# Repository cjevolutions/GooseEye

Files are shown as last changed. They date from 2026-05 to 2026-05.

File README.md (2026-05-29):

# GooseEye hardware — **start here**

You are in the right place. This repository is a **step-by-step kit** for building the GooseEye truck-bed distance sensor: a small box with a laser rangefinder and a Bluetooth chip that talks to the GooseEye phone app (the app is **not** in this repo).

**You do not need** prior experience with GitHub or programming. You **do** need the capabilities below — read them **before** you buy parts.

---

## Requirements (read this before ordering parts)

If you cannot check off every **must have** row, finish that gap first or this build will stall halfway.

### Must have

| Requirement | What it means for you |
|---|---|
| **A 3D-printed enclosure** | The sensor box is **not** sold ready-made. You get a free computer model ([`v3 Case.step`](docs/v3%20Case.step)) and must produce a physical plastic case using **one** of the options below. |
| **3D printer *or* print service** | **Option A — Own printer:** FDM printer (Bambu, Prusa, Creality, etc.), slicer software, and filament (**PETG** or **ASA** recommended for sun/heat in a truck bed). **Option B — No printer:** Upload the file to an online print service (e.g. [Craftcloud](https://craftcloud3d.com/)) or a local makerspace/library and pay someone to print it. Budget roughly **$15–60 USD** for a service print, plus shipping and wait time. → **[How to print the case](docs/PRINT-THE-CASE.md)** |
| **Soldering** | Every wire between the truck power, converter, ESP32, MOSFET, and LiDAR is **soldered**. You need a soldering iron, solder, and heat-shrink (or tape). First-time solderers can do this — plan a slow evening. |
| **Computer (once)** | Mac or Windows PC with internet, to install **PlatformIO** and run **one copy-paste command** that loads firmware onto the ESP32. A **USB-C data cable** (not charge-only) connects the board to the PC. |
| **Truck 12 V power** | A fused tap on the vehicle **12 V** accessory/battery circuit to feed the buck converter. Wiring with the **engine off** for the first hookup. |
| **Smartphone with Bluetooth** | To test the sensor (free apps: **nRF Connect** or **LightBlue**). The GooseEye **phone app** is separate from this repo but is what you use day-to-day when driving. |
| **Basic hand tools** | Wire stripper, screwdriver for **2 mm** LiDAR screws, multimeter strongly recommended. |

### Strongly recommended

| Item | Why |
|---|-----|
| **Inline fuse** on 12 V | Protects the truck wiring if something shorts |
| **Silicone sealant** + optional **hot glue gun** | Seals lid gaps and the wire exit against rain/dust |
| **Help or a second pair of hands** | Holding wires while soldering is easier with two people |

### You do **not** need

- A GitHub account (you can download a ZIP)
- Programming experience (no code to write)
- A machine shop or CNC (printing is enough)
- To understand the text inside the `.step` file ([that is not code](docs/PRINT-THE-CASE.md))

### Time and cost (rough planning)

| | Estimate |
|---|---|
| **Your time** | One **weekend** if new to soldering; faster if experienced |
| **Amazon electronics** | About **$80–150 USD** depending on what you already own |
| **Case** | Filament + electricity if self-printed; **$15–60+** if using a print service |
| **Tools one-time** | Iron + solder + multimeter if you do not own them |

**Ready?** Continue to the [parts shopping list](#parts-to-order-shopping-list) below, then the [build path](#the-build-path--follow-in-order).

---

## Parts to order (shopping list)

Order these **after** the [requirements](#requirements-read-this-before-ordering-parts) above make sense for you. Check each box when it arrives.

| | Part | Qty | Notes | Where to buy |
|---|---|:---:|---|---|
| ☐ | Benewake waterproof TFmini LiDAR | 1 | 4-wire UART rangefinder | [**Amazon →**](https://www.amazon.com/Benewake-Distance-Waterproof-Anti-dust-Raspberry/dp/B08D3D63QZ) |
| ☐ | Seeed XIAO ESP32-S3 | 1 | Includes snap-on **U.FL WiFi antenna** | [**Amazon →**](https://www.amazon.com/ESP32S3-2-4GHz-Dual-core-Supported-Efficiency-Interface/dp/B0BYSB66S5) |
| ☐ | DC buck converter (12 V → 5 V) | 1 | Adjust trim to **5.00 V** before load | [**Amazon →**](https://www.amazon.com/dp/B0F1WB3LJ5) |
| ☐ | MOSFET switch module | 1 | Switches LiDAR power in sleep mode | [**Amazon →**](https://www.amazon.com/dp/B0DZP27C2N) |
| ☐ | Wire (main harness) | 1 roll | Match gauge to your truck run length | [**Amazon →**](https://www.amazon.com/dp/B0C5T5G2NH) |
| ☐ | 3D-printed case (v3) | 1 | Print at home **or** use a print service — not sold on Amazon | [**How to print**](docs/PRINT-THE-CASE.md) · [**Download file**](https://github.com/cjevolutions/GooseEye/raw/main/docs/v3%20Case.step) |
| ☐ | 2 mm screws (LiDAR to case) | 4+ | Length ≈ 6–12 mm for your print | [**Amazon (example pack) →**](https://www.amazon.com/s?k=m2+screw+kit) · hardware store |

**Also pick up** (soldering, sealing, truck install)

| | Item | Why | Where to buy |
|---|---|-----|---|
| ☐ | Soldering iron + solder + heat-shrink | Wire joints | [**Amazon (kit example) →**](https://www.amazon.com/s?k=soldering+iron+kit) · [tool details](docs/ASSEMBLY.md#3-tools-and-supplies) |
| ☐ | USB-C **data** cable | Flash firmware — not charge-only | [**Amazon (USB-C data cable) →**](https://www.amazon.com/s?k=usb-c+data+cable) |
| ☐ | Multimeter | Check 5 V before powering boards | [**Amazon →**](https://www.amazon.com/s?k=digital+multimeter) |
| ☐ | Silicone sealant (100% silicone, clear outdoor) | Seal lid + wire exit | [**Amazon →**](https://www.amazon.com/s?k=clear+silicone+sealant+outdoor) |
| ☐ | Hot glue gun + glue sticks | Optional extra sealing | [**Amazon →**](https://www.amazon.com/s?k=hot+glue+gun) |
| ☐ | Inline blade fuse + holder (12 V) | Strongly recommended | [**Amazon →**](https://www.amazon.com/s?k=12v+blade+fuse+holder+inline) |
| ☐ | PETG or ASA filament | **Only if you print the case at home** | [**Amazon (PETG example) →**](https://www.amazon.com/s?k=petg+filament+1.75) |
| ☐ | Online 3D print service | **If you do not own a printer** | [Craftcloud](https://craftcloud3d.com/) · [Shapeways](https://www.shapeways.com/) |

Full detail and optional items: [Assembly guide §4 — Bill of materials](docs/ASSEMBLY.md#4-bill-of-materials)

**When parts arrive →** start the [build path](#the-build-path--follow-in-order) at step **0**.

### About the case file (`v3 Case.step`)

That file is a **3D blueprint**, not program code. If GitHub shows a wall of text, **close the tab** and open **[How to print the case](docs/PRINT-THE-CASE.md)** — it explains download, slicer, and print orientation in plain language.

---

## What you are making (30 seconds)

A waterproof LiDAR measures distance to your trailer. A **Seeed XIAO ESP32-S3** board sends that distance over **Bluetooth** to your phone. Everything runs from your truck’s **12 V** power, converted to safe **5 V** inside a **3D-printed case** you provide (home printer or print service). You will **solder wires** and **plug the board into your computer once** to load the firmware.

---

## New to GitHub? You only need the files

You **do not** need a GitHub account to build this. You do **not** need to learn git.

**Option A — Download as ZIP (easiest)**

1. Open this page: [github.com/cjevolutions/GooseEye](https://github.com/cjevolutions/GooseEye)
2. Click the green **Code** button.
3. Click **Download ZIP**.
4. Double-click the ZIP on your computer to unpack it.
5. You now have a folder named `GooseEye-main` (or similar). **That folder is your project.** All paths below assume you are inside it.

**Option B — Clone (only if you already use git)**

```text
git clone git@github.com:cjevolutions/GooseEye.git
cd GooseEye
```

The rest of this README lives inside that folder.

---

## The build path — follow in order

Check off each step. **Next** links take you to the right document and section.

| Step | What you do | Open this next |
|:----:|---|---|
| **0** | Confirm [requirements](#requirements-read-this-before-ordering-parts) & read safety | → [Safety & tools](docs/ASSEMBLY.md#2-safety) |
| **1** | Buy / gather all parts | → [Shopping list](#parts-to-order-shopping-list) · [Full BOM](docs/ASSEMBLY.md#4-bill-of-materials) |
| **2** | See what connects to what (read before soldering) | → [Wiring diagram](docs/wiring-diagram.md) |
| **3** | Print the enclosure | → [**Print the case — start here**](docs/PRINT-THE-CASE.md) (then [assembly §9](docs/ASSEMBLY.md#9-enclosure-assembly-v3-case)) |
| **4** | Snap on WiFi antenna, then solder the harness | → [Soldering steps](docs/ASSEMBLY.md#7-soldering-the-harness) |
| **5** | Power on at the bench (no truck install yet) | → [Bench test](docs/ASSEMBLY.md#8-bench-test-before-truck-install) |
| **6** | Install the flash tool on your computer | → [Install PlatformIO](docs/ASSEMBLY.md#install-platformio) |
| **7** | Load firmware onto the XIAO (one script) | → [Flash firmware](docs/ASSEMBLY.md#upload) + [Script help](#running-the-flash-script-first-timers) below |
| **8** | Confirm Bluetooth with your phone | → [Verify BLE](docs/ASSEMBLY.md#11-verify-ble) |
| **9** | Mount parts in the case | → [Enclosure assembly](docs/ASSEMBLY.md#9-enclosure-assembly-v3-case) |
| **10** | Install in the truck | → [Truck installation](docs/ASSEMBLY.md#12-truck-installation) |
| **11** | Something wrong? | → [Troubleshooting](docs/ASSEMBLY.md#13-troubleshooting) |

**Full single document (printable):** [docs/ASSEMBLY.md](docs/ASSEMBLY.md) — same content as the table above, with more detail in each section.

---

### Step 0 → Start the assembly guide

Open **[docs/ASSEMBLY.md — section 1](docs/ASSEMBLY.md#1-what-you-are-building)** and read sections **1 (what you are building)** and **2 (safety)**.

Then continue to **section 3 (tools)**. Order anything missing from the [shopping list above](#parts-to-order-shopping-list).

**Next:** [Wiring diagram →](docs/wiring-diagram.md)

---

### Step 2 → Wiring (look at diagrams before you solder)

Open **[docs/wiring-diagram.md](docs/wiring-diagram.md)**. You do not need to memorize it; keep it open while you solder.

Key idea: truck **12 V** → **buck converter** → **5 V** to the XIAO **5V / VBUS** pad (board may say **VBUS**, not “5V”) and to a **MOSFET** that switches LiDAR power. UART wires go XIAO **D9/D10** ↔ LiDAR white/green.

**Next:** [Print the case →](docs/ASSEMBLY.md#3d-printing-the-case)

---

### Step 4 → Soldering & antenna

In **[docs/ASSEMBLY.md section 7](docs/ASSEMBLY.md#7-soldering-the-harness)**:

1. **[§7.0](docs/ASSEMBLY.md#step-70--xiao-wifi-antenna-before-wiring)** — Press the small **U.FL antenna** onto the tiny RF port on the XIAO (press straight down; it will feel stiff until it snaps).
2. **§7.1–7.6** — Solder buck, XIAO power, MOSFET, and LiDAR wires.

**Next:** [Bench test →](docs/ASSEMBLY.md#8-bench-test-before-truck-install)

---

### Steps 6–7 → Computer setup and firmware

You are **loading a program** onto the XIAO so it can speak Bluetooth. You are not “coding” — you run one prepared script.

1. Read **[Install PlatformIO](docs/ASSEMBLY.md#install-platformio)** in the assembly guide (Mac: Homebrew; Windows: installer from platformio.org).
2. Plug in the XIAO with a **USB-C data cable** (not charge-only).
3. Follow **[Upload / flash](docs/ASSEMBLY.md#upload)** or use the [script instructions below](#running-the-flash-script-first-timers).

**Next:** [Verify BLE on your phone →](docs/ASSEMBLY.md#11-verify-ble)

---

### Steps 9–10 → Case and truck

**[Enclosure assembly](docs/ASSEMBLY.md#9-enclosure-assembly-v3-case)** — LiDAR on **2 mm screws**, electronics inside, lid against the truck bed, wire out the bottom. Then **[seal gaps with silicone and/or a hot glue gun](docs/ASSEMBLY.md#weather-sealing-silicone-andor-hot-glue)** (lid seam, wire exit, pinholes) before the truck gets wet.

**[Truck installation](docs/ASSEMBLY.md#12-truck-installation)** — fuse, strain relief, clear line of sight to the trailer.

---

## Running the flash script (first timers)

A **script** is a small file of instructions for your computer. You open a **terminal** (text window), go to the project folder, and paste one command. The computer builds and uploads the firmware to the XIAO.

### Mac

1. Open **Terminal** (Spotlight: type `Terminal`, press Enter).
2. Go to your project folder (adjust the path if your folder is on the Desktop):

```bash
cd ~/Downloads/GooseEye-main
```

If you unpacked the ZIP somewhere else, drag the folder into the Terminal window after typing `cd ` — it will fill in the path.

3. Allow the script to run (only needed once):

```bash
chmod +x scripts/flash-firmware.sh
```

4. Run the flasher:

```bash
./scripts/flash-firmware.sh
```

5. Wait until it says **Done**. If it cannot find the board, unplug/replug USB or see [Troubleshooting](docs/ASSEMBLY.md#13-troubleshooting).

**What `chmod` means:** “This file is allowed to run.” **What `./scripts/...` means:** “Run the flash script in the `scripts` folder.”

### Windows

1. Install [PlatformIO](https://platformio.org/install/cli) first (see assembly guide).
2. Open **PowerShell** or **Command Prompt**.
3. Go to the folder:

```powershell
cd Downloads\GooseEye-main
```

4. Run PlatformIO directly (Windows does not require `chmod`):

```powershell
cd firmware
pio run -t upload
```

If upload fails, open Device Manager, note the **COM port** (e.g. `COM5`), then:

```powershell
pio run -t upload --upload-port COM5
```

### Success check

- No red error text at the end.
- Optional: `cd firmware` then `pio device monitor` — you should see `[GooseEye] boot` in the log.

**Next step:** [Verify BLE with your phone →](docs/ASSEMBLY.md#11-verify-ble)

---

## Words you might see (quick glossary)

| Term | Plain meaning |
|---|---|
| **GitHub** | Website where this project files are hosted |
| **Repository / repo** | This project’s folder of files |
| **Firmware** | Program inside the XIAO |
| **BLE / Bluetooth** | How the sensor talks to the phone |
| **Buck converter** | Lowers 12 V to 5 V |
| **MOSFET module** | Electronic switch that turns LiDAR power on/off |
| **U.FL antenna** | Small snap-on WiFi antenna for Bluetooth range |
| **PlatformIO** | Free tool that installs and uploads firmware |
| **Terminal** | Mac text window for typing commands |
| **D9, D10, D1** | Pin names printed on the XIAO board |
| **5V / VBUS** | Pad where regulated 5 V power goes in |

---

## Reference documents

| Document | When to use it |
|---|---|
| [docs/ASSEMBLY.md](docs/ASSEMBLY.md) | Main build manual (all steps) |
| [docs/wiring-diagram.md](docs/wiring-diagram.md) | While soldering |
| [docs/PRINT-THE-CASE.md](docs/PRINT-THE-CASE.md) | **How to use the case file** (download, slicer, orientation) |
| [docs/v3 Case.step](docs/v3%20Case.step) | 3D model only — [download raw file](https://github.com/cjevolutions/GooseEye/raw/main/docs/v3%20Case.step) (use the guide if you see “code”) |
| [docs/ble-protocol.md](docs/ble-protocol.md) | Only if you integrate without the official app |
| [firmware/](firmware/) | Source code (you do not need to edit this) |

---

## Help

- **Stuck on a step?** [Troubleshooting](docs/ASSEMBLY.md#13-troubleshooting)
- **Issue with this documentation?** Open an issue on [github.com/cjevolutions/GooseEye/issues](https://github.com/cjevolutions/GooseEye/issues)

---

## For maintainers (skip if you are building hardware)

Sync firmware from the private monorepo: `./scripts/prepare-publish.sh`  
Push notes: [PUSH.md](PUSH.md)

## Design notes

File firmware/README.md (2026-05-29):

# Goose Eye Firmware

PlatformIO firmware for the **Seeed Studio XIAO ESP32-S3** + **Benewake TFmini-S / TFmini Plus** LiDAR sensor.

Hardware assembly and wiring: see the [GooseEye hardware repo](https://github.com/cjevolutions/GooseEye) `docs/ASSEMBLY.md` (or `gooseeye-hardware/docs/` in the monorepo).

## Hardware pins

| XIAO pin | GPIO | Connection |
|---|---|---|
| 5V / VBUS | — | Buck 5 V (USB rail; silkscreen may say VBUS — not 3V3) |
| GND | — | Common ground with buck, LiDAR, MOSFET |
| D9 | 8 | TFmini white (RX) — ESP UART TX |
| D10 | 9 | TFmini green (TX) — ESP UART RX |
| D1 | 2 | MOSFET module IN (LiDAR VCC high-side switch) |
| LED | 21 | Built-in status LED (breathe in sleep) |

LiDAR **red (VCC)** is fed from the MOSFET switched output, not directly from the buck.

## Build & flash

```bash
cd firmware
pio run                 # build
pio run -t upload       # flash (USB)
pio device monitor      # serial console @ 115200
```

From the monorepo root: `./scripts/flash-firmware.sh`

## BLE protocol

Service UUID `4e6f7365-4579-6500-0000-000000000000`. Full definitions in [`include/protocol.h`](include/protocol.h).

| Char | Suffix | Properties | Purpose |
|---|---|---|---|
| Distance | `...0001...` | Notify / Read | 6-byte `ge_distance_payload_t` @ 20 Hz |
| Device Info | `...0002...` | Read | JSON: name, firmware, mac, uptime |
| Device Config | `...0003...` | Read / Write | JSON: writable name, frame rate |
| OTA Control | `...0004...` | Write / Notify | Update lifecycle + status |
| OTA Data | `...0005...` | Write w/o Resp. | Firmware bytes in ≤240 B chunks |
| Factory Reset | `...0006...` | Write | Magic `DE AD BE EF` clears NVS |
| Session | `...0007...` | Write | `0x01` keep awake while app foreground |

## Power behavior

- **Awake:** BLE connected, app session keep-alive within 5 s, OTA idle → LiDAR rail on, UART active, distance notify @ 20 Hz.
- **Sleep:** disconnect or no keep-alive for 2 s → LiDAR rail off (MOSFET), UART off, status LED breathes, BLE still advertises.
- No ESP deep sleep; the radio stays up for reconnect.

## Versioning

Set in [`platformio.ini`](platformio.ini) via `FIRMWARE_VERSION_*` build flags. Exposed on the Device Info characteristic.

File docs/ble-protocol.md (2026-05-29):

# GooseEye BLE protocol

Human-readable summary of the firmware GATT service. Canonical definitions live in [`firmware/include/protocol.h`](../firmware/include/protocol.h).

## Service

| | UUID |
|---|---|
| Primary service | `4e6f7365-4579-6500-0000-000000000000` |

Advertised name defaults to **GooseEye** (NVS-overridable via Device Config).

## Characteristics

| Name | UUID suffix | Properties | Purpose |
|---|---|---|---|
| Distance | `...0001...` | Notify, Read | 6-byte distance payload @ 20 Hz when streaming |
| Device Info | `...0002...` | Read | JSON: name, firmware version, MAC, uptime |
| Device Config | `...0003...` | Read, Write | JSON: writable name, frame rate |
| OTA Control | `...0004...` | Write, Notify | Firmware update commands and status |
| OTA Data | `...0005...` | Write Without Response | Firmware binary chunks (max 240 B) |
| Factory Reset | `...0006...` | Write | Magic bytes `DE AD BE EF` → clear NVS, reboot |
| Session | `...0007...` | Write | `0x01` = keep awake, `0x00` = allow sleep |

Full UUID form: `4e6f7365-4579-6500-00XX-000000000000` where `XX` is the suffix above.

## Distance payload (6 bytes, little-endian)

| Offset | Field | Type | Description |
|---|---|---|---|
| 0–1 | distance_mm | uint16 | Millimeters; 0 = invalid |
| 2–3 | strength | uint16 | TFmini signal strength |
| 4 | quality | uint8 | Derived 0–100 |
| 5 | flags | uint8 | Bit0 out_of_range, Bit1 too_close, Bit2 smoothed |

## Session / sleep behavior

| Constant | Value | Meaning |
|---|---|---|
| Keep awake | `0x01` | App foreground — stay awake |
| Allow sleep | `0x00` | App backgrounded |
| Session timeout | 5 s | No keep-alive write → treat as background |
| Sleep enter delay | 2 s | After disconnect/no session → sleep |

**Sleep:** LiDAR power off (MOSFET), UART off, status LED breathes, BLE still advertises.

**Awake:** BLE connected + session keep-alive within 5 s + OTA idle → LiDAR on, notifications at 20 Hz.

## OTA (optional integrators)

| Command | Byte | Payload |
|---|---|---|
| START | `0x01` | uint32 size, uint32 CRC32 |
| ABORT | `0x02` | — |
| VERIFY | `0x03` | — |

Status notifications: READY `0xA0`, PROGRESS `0xA1`, ERROR `0xA2`, SUCCESS `0xA3`.

## Testing without the mobile app

Use **nRF Connect** or **LightBlue**:

1. Scan for **GooseEye**.
2. Connect and subscribe to Distance notifications.
3. Write `0x01` to Session characteristic to simulate foreground (otherwise device sleeps after ~2 s when connected without keep-alive, depending on connection state).

For full integration, use the GooseEye mobile app (not in this repository).

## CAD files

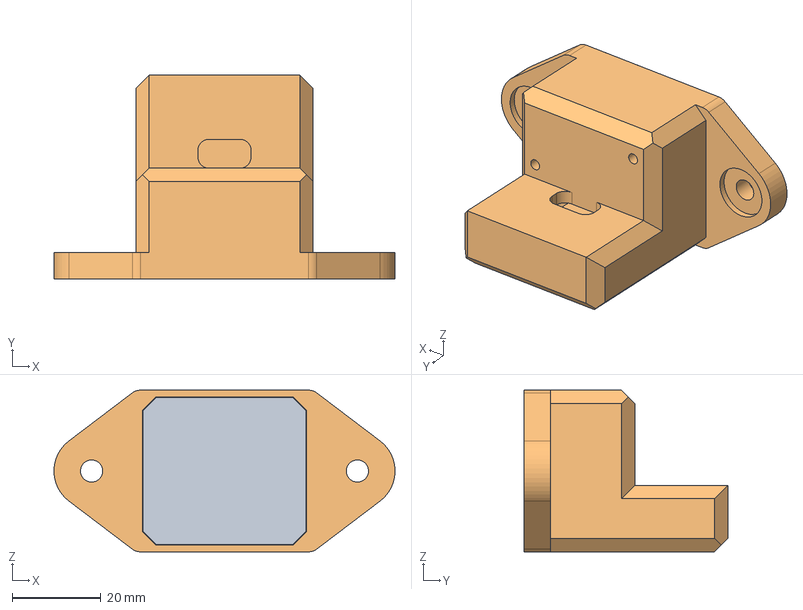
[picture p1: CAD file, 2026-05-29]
docs/v3 Case.step
77.0 x 46.0 x 36.5 mm

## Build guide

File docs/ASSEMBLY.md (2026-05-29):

# GooseEye hardware assembly guide

> **Start on GitHub?** Read [README requirements](../README.md#requirements-read-this-before-ordering-parts) and the [shopping list](../README.md#parts-to-order-shopping-list) **before** ordering. Then follow the [build path](../README.md#the-build-path--follow-in-order).

This guide walks you through building the GooseEye truck-bed distance sensor from scratch. **You will solder wires** — there are no pre-made harness connectors in the bill of materials. Take your time; bad joints cause intermittent power and UART failures.

The companion mobile app is **not** in this repository. This repo is firmware + hardware only.

### Guide map (in order)

| § | Topic | Jump |
|---|---|---|
| 1 | What you are building | [Below](#1-what-you-are-building) |
| 2 | Safety | [§2](#2-safety) |
| 3 | Tools | [§3](#3-tools-and-supplies) |
| 4 | Parts to buy | [§4](#4-bill-of-materials) |
| 5 | Voltages | [§5](#5-voltage-and-current) |
| 6 | Wiring overview | [§6](#6-wiring-overview) → [full diagram](wiring-diagram.md) |
| 7 | Soldering | [§7](#7-soldering-the-harness) |
| 8 | Bench test | [§8](#8-bench-test-before-truck-install) |
| 9 | 3D print & case | [Print guide](PRINT-THE-CASE.md) · [§9](#9-enclosure-assembly-v3-case) |
| 10 | Flash firmware | [§10](#10-flash-firmware) |
| 11 | Test Bluetooth | [§11](#11-verify-ble) |
| 12 | Truck install | [§12](#12-truck-installation) |
| 13 | Troubleshooting | [§13](#13-troubleshooting) |

---

## 1. What you are building

A waterproof Benewake TFmini-class LiDAR talks to a Seeed XIAO ESP32-S3 over UART. The ESP32 advertises distance over Bluetooth Low Energy (BLE) as **GooseEye**. A 12 V → 5 V buck converter powers the board from the truck; a MOSFET module switches LiDAR power off when the firmware sleeps to save energy.

Electronics live inside the **v3 printed case** ([`v3 Case.step`](v3%20Case.step)): the LiDAR bolts on with **2 mm screws**, the buck and MOSFET are fitted loosely inside, and the truck harness exits the **bottom**. The **lid** is the face that mounts **against the truck bed**.

**Next:** [§2 Safety →](#2-safety)

---

## 2. Safety

- **12 V automotive wiring** can supply high current. Use an **inline fuse** on the 12 V feed (5–10 A blade fuse is a reasonable starting point; size to your tap and wire gauge).
- Work with the vehicle **off** or the circuit **unplugged** while soldering and doing first power-up on the bench.
- The LiDAR is a Class 1 eye-safe laser product when used as specified; do not stare into the aperture at close range.
- **ESD:** touch a grounded metal surface before handling the XIAO or LiDAR PCB.
- **5 V only** on the XIAO power pad and LiDAR VCC. **Never connect 12 V** to the ESP32 or sensor.

**Next:** [§3 Tools & supplies →](#3-tools-and-supplies)

---

## 3. Tools and supplies

| Tool / supply | Purpose |
|---|---|
| Soldering iron (temperature-controlled, ~350°C / 660°F for lead-free) | Joints |
| Solder (rosin core) | Joints |
| Heat-shrink tubing (assorted) | Insulate joints |
| Wire stripper | Prepare wire ends |
| Multimeter | Verify 5 V, continuity, polarity |
| USB-C **data** cable | Flash firmware and serial debug |
| PC with PlatformIO | Build and upload firmware |
| Optional: helping hands, flux, isopropyl alcohol | Easier soldering and cleanup |
| **2 mm** screwdriver or hex driver | LiDAR screws into case |
| **Silicone sealant** (clear outdoor / RV / aquarium-grade) | Seal lid gaps, wire exit, and print layer lines |
| **Hot glue gun** + glue sticks | Optional: tack wires, fill small gaps, backup seal |
| Calipers / CAD viewer | Check printed case against STEP model |

**Next:** [§4 Parts list (order these) →](#4-bill-of-materials)

---

## 4. Bill of materials

| Part | Notes | Where to buy |
|---|---|---|
| Benewake waterproof TFmini LiDAR | TFmini-S / Plus class; 4-wire UART | [**Amazon →**](https://www.amazon.com/Benewake-Distance-Waterproof-Anti-dust-Raspberry/dp/B08D3D63QZ) |
| Seeed XIAO ESP32-S3 | 2.4 GHz, USB-C; includes **U.FL WiFi antenna** | [**Amazon →**](https://www.amazon.com/ESP32S3-2-4GHz-Dual-core-Supported-Efficiency-Interface/dp/B0BYSB66S5) |
| DC buck converter (12 V → 5 V) | **One** module; adjust trim to **5.00 V** before load | [**Amazon →**](https://www.amazon.com/dp/B0F1WB3LJ5) |
| MOSFET switch module | High-side LiDAR VCC; control on D1 | [**Amazon →**](https://www.amazon.com/dp/B0DZP27C2N) |
| Wire | Main harness gauge per your run length | [**Amazon →**](https://www.amazon.com/dp/B0C5T5G2NH) |
| Printed enclosure (v3 case) | Print or use a service — [PRINT-THE-CASE.md](PRINT-THE-CASE.md) | [**Download STEP**](https://github.com/cjevolutions/GooseEye/raw/main/docs/v3%20Case.step) |
| **2 mm screws** (LiDAR to case) | Typically 6–12 mm length for your print | [**Amazon search →**](https://www.amazon.com/s?k=m2+screw+kit) |

Same list with checkboxes: [README shopping list](../README.md#parts-to-order-shopping-list).

### Recommended (with buy links)

| Item | Where to buy |
|---|---|
| Inline **blade fuse** + holder on 12 V | [**Amazon search →**](https://www.amazon.com/s?k=12v+blade+fuse+holder+inline) |
| **USB-C data cable** (flash firmware) | [**Amazon search →**](https://www.amazon.com/s?k=usb-c+data+cable) |
| Soldering iron, solder, heat-shrink | [**Amazon (kit example) →**](https://www.amazon.com/s?k=soldering+iron+kit) |
| Silicone sealant + optional hot glue | [**Silicone →**](https://www.amazon.com/s?k=clear+silicone+sealant+outdoor) · [**Hot glue →**](https://www.amazon.com/s?k=hot+glue+gun) |
| **PETG/ASA filament** (if printing case) | [**PETG example →**](https://www.amazon.com/s?k=petg+filament+1.75) |
| **Print service** (no home printer) | [Craftcloud](https://craftcloud3d.com/) |
| Ferrules for 12 V tap (optional) | [**Amazon search →**](https://www.amazon.com/s?k=wire+ferrule+kit) |

Add photos of your finished build in `docs/images/` when you have them.

**Next:** [§5 Voltages →](#5-voltage-and-current) · [Wiring diagram (read before soldering) →](wiring-diagram.md)

---

## 5. Voltage and current

| Rail | Nominal | Notes |
|---|---|---|
| Vehicle input | 12 V DC (9–16 V typical) | Accessory circuit or battery; fused |
| Buck output | **5.0 V** | Adjust with no/minimal load, then recheck under load |
| XIAO | 5 V on **5V / VBUS** pad (see below) | Do not power from **3V3** — that is output only |
| TFmini VCC | 4.5–6 V | Fed from MOSFET switched 5 V |
| XIAO / LiDAR logic UART | 3.3 V tolerant | XIAO IO is 3.3 V; TFmini UART is 3.3 V CMOS |

**Current budget (planning):** ESP32-S3 + BLE ~100–250 mA peaks; TFmini ~100–300 mA peaks. Size the buck for **≥ 1 A** continuous on the 5 V output with headroom.

**Next:** [§6 Wiring overview →](#6-wiring-overview)

---

## 6. Wiring overview

See [wiring-diagram.md](wiring-diagram.md) for diagrams and tables.

Summary:

- **One buck:** 12 V in → 5 V out → XIAO **5V / VBUS** pad + MOSFET high-side input.
- **Shared ground:** buck, XIAO, MOSFET, LiDAR black.
- **LiDAR red** only to MOSFET switched output (not direct to buck).
- **UART:** XIAO D9 → white, D10 ← green.
- **Control:** XIAO D1 → MOSFET `IN`.

**Next:** Open [wiring-diagram.md](wiring-diagram.md), then [§7 Soldering →](#7-soldering-the-harness)

---

## 7. Soldering the harness

**You must solder** every connection below. Use heat shrink on each joint.

### Step 7.0 — XIAO WiFi antenna (before wiring)

The XIAO ESP32-S3 ships with a small **U.FL antenna** on a short coax pigtail. BLE range is poor without it — install it on the board **before** you solder power wires or stuff the board into the case.

1. Find the tiny **U.FL / IPEX** RF connector on the edge of the XIAO (metal snap fitting, smaller than a grain of rice).
2. Align the antenna connector squarely on top of the board connector.
3. **Press straight down** until it **snaps** into place. It is normal for this to feel **firm and a bit resistant** — use steady pressure with your fingernail or a plastic spudger, not sideways force.
4. Confirm both connectors are fully seated (no gap, antenna cable can move but the joint does not twist off easily).
5. Route the antenna **away from the LiDAR UART wires and buck wiring** so nothing yanks the U.FL joint when you close the case. Let the antenna sit loosely inside the body — do not kink or crush the cable.

**Do not** power the board with a metal tool touching the U.FL contact. If the connector does not snap after several tries, check alignment; forcing it at an angle can damage the port.

### Step 7.1 — Prepare wires

1. Cut lengths with slack for mounting (bench-test short lengths first).
2. Strip ~3–5 mm (1/8–3/16 in) of insulation.
3. Tin the stripped ends with a small amount of solder.

### Step 7.2 — Buck converter

1. **Do not connect 12 V yet.**
2. Solder 12 V+ and 12 V− to the buck input pads (observe module silkscreen).
3. Solder 5 V+ and GND leads to the buck output pads.
4. On the bench, apply 12 V from a current-limited supply or vehicle tap (fused).
5. Turn the trim pot until the multimeter reads **5.00 V** at the output (no load or light load per module datasheet).

### Step 7.3 — XIAO power

On the Seeed XIAO ESP32-S3, the **5 V input pad is not always silkscreened as “5V”**. Look for **`5V`**, **`VBUS`**, or similar wording on the pin next to **`GND`** (same rail as USB-C 5 V). Do **not** wire the buck to **`3V3`** — that pin is regulated **output** only.

1. Solder buck 5 V+ → XIAO **5V / VBUS** pad.
2. Solder buck GND → XIAO **`GND`** pad.

If you will have **both** USB-C and the buck connected at once while bench-testing, Seeed recommends a **Schottky diode** from the buck (+) to this pad (anode toward buck, cathode toward the board) so the buck cannot back-feed the USB port. For truck install with USB unplugged, many builds omit the diode.

### Step 7.4 — MOSFET module

1. Buck 5 V+ → MOSFET **VIN+** (high-side in).
2. Buck GND → MOSFET **GND**.
3. MOSFET **OUT+** → LiDAR **red** (VCC).
4. LiDAR **black** → buck GND (same star ground as XIAO).
5. XIAO **D1** → MOSFET **IN** / control.

Confirm silkscreen on [your module](wiring-diagram.md#mosfet-module-labels); labels vary by seller.

### Step 7.5 — UART

1. XIAO **D9** → LiDAR **white** (RX on sensor).
2. XIAO **D10** → LiDAR **green** (TX on sensor).

Do not swap D9 and D10 — distance readings will fail.

### Step 7.6 — Quality check

- Tug-test each joint gently.
- Heat-shrink every exposed conductor.
- Verify **no short** between 5 V and GND with multimeter beep test before applying power.

**Next:** [§8 Bench test →](#8-bench-test-before-truck-install) · or print case first: [§9 Print enclosure →](#3d-printing-the-case)

---

## 8. Bench test (before truck install)

1. **Power off.** Connect USB-C to the XIAO for flashing only; truck 12 V can stay disconnected for first flash.
2. Flash firmware — [§10](ASSEMBLY.md#10-flash-firmware) or [README script walkthrough](../README.md#running-the-flash-script-first-timers).
3. Open serial monitor at **115200** baud. Expect:
   - `[GooseEye] boot`
   - `[GooseEye] advertising as GooseEye`
4. With 12 V bench power to the buck (LiDAR wired):
   - Measure **~5 V** between the XIAO **5V / VBUS** pad and **`GND`**.
   - Connect a phone BLE scanner; see **GooseEye** advertising.
5. **Sleep test:** disconnect BLE or wait ~2 s without session keep-alive. Serial should log `lidar power off`; multimeter on LiDAR red–black should drop to ~0 V. Reconnect with session `0x01` written to wake.

Flash firmware (Section 10) **before** closing the enclosure if you need USB access to the XIAO.

**Next:** [§9 Print & assemble case →](#9-enclosure-assembly-v3-case) · [§10 Flash firmware →](#10-flash-firmware)

---

## 9. Enclosure assembly (v3 case)

The truck-bed housing is a 3D-printed part from file **`v3 Case.step`**.

> **Clicked the file on GitHub and saw pages of text?** That is normal — it is not broken and you do not read that code. Follow **[PRINT-THE-CASE.md](PRINT-THE-CASE.md)** to download the file and open it in a **slicer** (printer software).

### 3D printing the case

**Full walkthrough (download, slicer, print service):** **[docs/PRINT-THE-CASE.md](PRINT-THE-CASE.md)**

Short version:

1. **Download** `v3 Case.step` to your computer ([ZIP from GitHub](../README.md#new-to-github-you-only-need-the-files) or [direct download](https://github.com/cjevolutions/GooseEye/raw/main/docs/v3%20Case.step)) — do not edit the text in a browser.
2. Open **PrusaSlicer**, **Bambu Studio**, **Cura**, or similar.
3. **Drag `v3 Case.step` into the slicer** — you should see a 3D box, not text.
4. **Print orientation:** **opening faces down on the build plate** (wire exit down, LiDAR end up).
5. Material: **PETG** or **ASA** for outdoor use. Slice, print, deburr screw bosses and wire exit.
6. Dry-fit the LiDAR before soldering the harness.

### Orientation (installed on the truck)

| Part | Role |
|---|---|
| **Lid** | **Back** of the enclosure — this face mounts **against the truck bed** |
| **Body** | Front / outer side — LiDAR looks out toward the trailer hookup area |
| **Bottom opening** | Main vehicle harness (12 V power + any slack) exits here |

```text
        [ LiDAR window ]
              |
    +-------------------+
    |      BODY         |  ---> toward trailer
    +-------------------+
    |       LID         |  ---> flat against truck bed
    +-------------------+
              |
         [ wire exit ]
```

### LiDAR mounting

1. Seat the LiDAR in the case front so the lens has a clear field of view.
2. Fasten with **2 mm screws** through the case bosses into the LiDAR mounting holes (do not overtighten into plastic threads).
3. Confirm the UART and power pigtails still reach the XIAO inside the body with gentle bends — no sharp kinks.

### Internal layout (buck, MOSFET, XIAO)

There are **no fixed mounting points** for the XIAO, buck converter, or MOSFET module in v3 — they are placed inside the body by hand:

- Confirm the **U.FL WiFi antenna** is snapped on and the cable is not pinched by the lid.
- Keep **12 V and 5 V wiring** away from the LiDAR window and UART wires.
- Avoid metal hardware touching bare converter or module pads.
- Leave enough slack on the **bottom exit** harness to service the unit without desoldering.
- Optional: secure loose boards with foam, zip ties to internal ribs, or double-sided tape on flat areas — do not block ventilation or the lid seal.

Route the soldered harness so the **main wire exits through the bottom** of the case before installing the lid.

### Weather sealing (silicone and/or hot glue)

The printed case will have **small gaps** at the lid seam, layer lines, and where the main wire exits the bottom. Truck-bed use means rain, spray, and dust — seal these **after** you have bench-tested and flashed the firmware (so you can still open the unit if something is wrong).

| Material | Good for | Avoid |
|---|---|---|
| **Silicone sealant** (clear, neutral-cure / “100% silicone”) | Lid perimeter, wire-exit grommet area, LiDAR window rim if there is a gap | Do not cover the LiDAR lens; do not seal the USB port if you still need access |
| **Hot glue gun** | Tacking the harness inside, filling pinholes, extra seal at wire exit | High heat near bare boards — glue **around** wires, not on chips |

**Suggested order**

1. Dry-fit the lid and mark where gaps are visible.
2. **Wire exit (bottom):** run a bead of **silicone** where the harness passes out — fill the gap but leave the wires movable for strain relief (don’t encapsulate 30 cm of cable).
3. **Lid seam:** with the lid seated, apply a thin **silicone** bead along the outside seam (truck-bed side and sides). Smooth with a gloved finger or tool. Wipe excess before it cures.
4. **Optional hot glue:** inside the case, blob glue where the wire bundle passes through the wall (from the inside) as a mechanical backup — not a substitute for silicone on the outside.
5. **Small print defects:** dot **silicone** or **hot glue** into pinholes or layer gaps that would let water in; keep glue away from the LiDAR aperture and antenna.

Let **silicone cure fully** per tube directions (often 24 hours) before mounting in the truck or blasting with a hose. Hot glue sets in minutes but is less durable long-term — treat it as backup unless you have no silicone.

**Do not** fill the entire case with glue or silicone; electronics must stay dry inside, and you may need to open the case later for USB service.

### Lid install

1. Tuck electronics so nothing interferes with the lid perimeter.
2. Close the **lid** (truck-bed side) and fasten per your print design (screws, clips, or sealant — follow whatever features are in your manufactured part).
3. Apply **silicone and/or hot glue** at gaps per [Weather sealing](#weather-sealing-silicone-andor-hot-glue) above.
4. Mount the assembly to the bed with the **lid against the truck** and the LiDAR facing the trailer.

**Next:** [§10 Flash firmware →](#10-flash-firmware) (if not done yet) · [README script help →](../README.md#running-the-flash-script-first-timers)

---

## 10. Flash firmware

This step **puts the GooseEye program on the XIAO**. You are not writing code — you install one free tool, then run the included script (or copy the commands from the [README](../README.md#running-the-flash-script-first-timers)).

**Before you start:** XIAO plugged in with a **USB-C data cable** (chargers-only cables will not work).

### Install PlatformIO

**PlatformIO** is a command-line tool that compiles and uploads firmware. Install it once per computer.

| Computer | What to do |
|---|---|
| **Mac** | Open Terminal. If you have [Homebrew](https://brew.sh): run `brew install platformio`. If not, use the [PlatformIO installer](https://platformio.org/install/cli). |
| **Windows** | Download and run the installer from [platformio.org/install/cli](https://platformio.org/install/cli). Close and reopen PowerShell after install. |

**Check it worked:** open Terminal or PowerShell and type:

```bash
pio --version
```

You should see a version number, not “command not found.”

### Upload

**Easiest path:** follow [README — Running the flash script](../README.md#running-the-flash-script-first-timers) (copy-paste friendly).

**Or**, from the **repository root** folder (the one that contains `scripts/` and `docs/`):

```bash
chmod +x scripts/flash-firmware.sh
./scripts/flash-firmware.sh
```

(`chmod` is Mac/Linux only — tells the computer the script is allowed to run.)

macOS port is usually `/dev/cu.usbmodem*`. Override if needed:

```bash
UPLOAD_PORT=/dev/cu.usbmodem143201 ./scripts/flash-firmware.sh
```

Windows: open **Device Manager** → **Ports (COM & LPT)** → note **COM5** (example), then in PowerShell from the repo folder:

```powershell
cd firmware
pio run -t upload --upload-port COM5
```

### Serial monitor

Optional — shows text logs from the board:

```bash
cd firmware
pio device monitor
```

Press `Ctrl+C` to exit. You should see `[GooseEye] boot`.

### Bootloader mode

If upload fails: double-tap the XIAO **RESET** button quickly; the board enters USB bootloader mode. Retry upload.

**Next:** [§11 Verify BLE on your phone →](#11-verify-ble)

---

## 11. Verify BLE

1. Install **nRF Connect** (iOS/Android) or **LightBlue**.
2. Scan and connect to **GooseEye**.
3. Subscribe to the Distance characteristic (`...0001...`).
4. Write **`0x01`** to the Session characteristic (`...0007...`) to keep the device awake (see [ble-protocol.md](ble-protocol.md)).
5. Wave a hand in front of the LiDAR; distance notifications should update.

**Next:** [§9 Enclosure →](#9-enclosure-assembly-v3-case) if not built yet · [§12 Truck install →](#12-truck-installation)

---

## 12. Truck installation

1. Confirm **silicone has cured** and seals at the lid and wire exit are intact (see [weather sealing](#weather-sealing-silicone-andor-hot-glue)).
2. Mount the **lid (back) flush against the truck bed**; the LiDAR window should face the trailer hitch area with clear line of sight.
3. Strain-relief the harness where it exits the **bottom** of the case and at the 12 V tap.
4. Route wiring away from exhaust, heat, and moving parts.
5. Re-check **5 V** under load with the engine on (alternator may raise rail voltage).
6. After sealing the case, firmware updates require USB access to the XIAO — plan ahead or open the enclosure.

**Next:** [§13 Troubleshooting →](#13-troubleshooting) · [Back to README start →](../README.md)

---

## 13. Troubleshooting

| Symptom | Likely cause | Fix |
|---|---|-----|
| No USB port for flash | Charge-only cable | Use data-capable USB-C |
| Upload fails | Wrong port / not in bootloader | Set `UPLOAD_PORT`; double-tap RESET |
| No BLE advertisement | Bad flash, power, missing antenna | Reflash; check 5 V; snap U.FL antenna onto RF port |
| BLE very weak / drops at short range | Antenna not seated or crushed in case | Reseat U.FL connector; reroute antenna cable |
| BLE connects, no distance | Sleep mode, no session | Write `0x01` to Session char |
| Distance always invalid | D9/D10 swapped | Swap white/green UART |
| LiDAR always off | D1 wrong; active-low module | Rewire D1; rebuild with inverted flag (below) |
| LiDAR always on in sleep | MOSFET wired on wrong terminals | Review high-side diagram |
| 5 V low under load | Buck underrated / bad trim | Re-trim at load; larger buck |

### Inverted MOSFET control

If your module turns the load **on** when D1 is LOW, add to `firmware/platformio.ini` under `build_flags`:

```
-DGE_LIDAR_POWER_ACTIVE_HIGH=0
```

Rebuild and reflash.

---

## 14. Firmware pin reference

| XIAO label | GPIO | Function |
|---|---|---|
| D9 | 8 | UART TX → LiDAR RX |
| D10 | 9 | UART RX ← LiDAR TX |
| D1 | 2 | LiDAR power MOSFET control |
| 5V / VBUS + GND | — | 5 V power in (not 12 V; not 3V3) |

Firmware version is in `firmware/platformio.ini` (`FIRMWARE_VERSION_*`).

---

## 15. Next steps

- Add photos of your printed case and bed mount to `docs/images/`.
- Integrate with the GooseEye mobile app (distributed separately).
- Report hardware issues on the [GitHub issue tracker](https://github.com/cjevolutions/GooseEye/issues).

**Back to top:** [README — start here →](../README.md)

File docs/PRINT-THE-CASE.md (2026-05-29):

# How to print the v3 case (read this if the link looked like “code”)

If you clicked **`v3 Case.step`** on GitHub and saw **thousands of lines of text** — nothing is broken. That page is the raw 3D model data. **Do not try to read, edit, or copy it.** You are not supposed to understand that text.

**What you actually do:** save the file to your computer, open a **3D printer slicer** app, drag the file in, and print the plastic box (or send the file to a print shop).

**Previous:** [Requirements — need a printer or print service](../README.md#requirements-read-this-before-ordering-parts) · **Next:** [Soldering](ASSEMBLY.md#7-soldering-the-harness)

---

## What is this file?

| | |
|---|---|
| **File name** | `v3 Case.step` |
| **Type** | STEP — a standard **3D shape** file (like a digital blueprint) |
| **Used for** | 3D printing the enclosure that holds the LiDAR and ESP32 |
| **Not used for** | Opening in a text editor, the firmware, or the phone app |

---

## Step 1 — Get the file on your computer

Pick **one** method.

### Method A — Download ZIP of the whole project (easiest on GitHub)

1. Go to [github.com/cjevolutions/GooseEye](https://github.com/cjevolutions/GooseEye).
2. Click green **Code** → **Download ZIP**.
3. Unzip the folder on your computer.
4. Open the folder → `docs` → you will see **`v3 Case.step`** (a single file, a few MB).

### Method B — Direct download (one file only)

1. Click this link (it should **download**, not show text in the browser):  
   **[Download `v3 Case.step`](https://github.com/cjevolutions/GooseEye/raw/main/docs/v3%20Case.step)**
2. If your browser still opens a text page: press **Ctrl+S** (Windows) or **Cmd+S** (Mac) and save as `v3 Case.step`, **or** right-click the link → **Save link as…**.

### Method C — You already cloned or downloaded the repo

The file is at:

```text
GooseEye/docs/v3 Case.step
```

(on your machine, inside whatever folder you unzipped or cloned)

---

## Step 2 — Open a slicer (printer software)

A **slicer** turns the 3D model into instructions your printer understands (G-code). You need **one** of these on a computer — install free if you do not have one:

| Slicer | Typical printers |
|---|---|
| [Bambu Studio](https://bambulab.com/en/download/studio) | Bambu Lab |
| [PrusaSlicer](https://www.prusa3d.com/prusaslicer/) | Prusa, many others |
| [Cura](https://ultimaker.com/software/ultimaker-cura) | Creality, many others |
| MakerWorld / printer brand app | Varies |

**No 3D printer?** Skip to [Step 5 — Print service](#step-5--no-printer-use-a-print-service) below.

---

## Step 3 — Import the model (do not open in Notepad)

1. Launch your slicer.
2. **Drag `v3 Case.step` from your file manager into the slicer window.**  
   — or use **File → Import / Open** and choose `v3 Case.step`.
3. After a few seconds you should see a **3D view of a plastic box** — that is correct.

If the slicer says it cannot open STEP:

- Update the slicer to the latest version, **or**
- Open the file in [FreeCAD](https://www.freecad.org/) or [Tinkercad](https://www.tinkercad.com/), export as **STL**, then import the STL into your slicer.

---

## Step 4 — Set print orientation (important)

Place the model so the **large opening faces down onto the build plate** (the hole where wires exit points **down**; the LiDAR end points **up**).

```text
   build plate ═══════════════
        [ opening down ]
              ↑
         [ case body ]
```

This gives a flat base and fewer fragile overhangs. Your slicer may call this “lay flat on bed” — rotate the model until the open rim touches the plate.

**Material:** PETG or ASA recommended for sun/heat in a truck bed. PLA can work but may soften in hot weather.

Slice and print. Remove supports, clean the LiDAR screw holes and wire exit with a small knife or file if needed.

---

## Step 5 — No printer? Use a print service

1. Download `v3 Case.step` using [Step 1](#step-1--get-the-file-on-your-computer) above.
2. Upload the file to an online 3D printing service, for example:
   - [Craftcloud](https://craftcloud3d.com/)
   - [Shapeways](https://www.shapeways.com/)
   - Local makerspace / library with a printer
3. Choose **PETG** or **ASA** if offered for outdoor use.
4. Mention in notes: **opening must sit on the build plate** (same orientation as Step 4).

---

## Step 6 — After the print

Continue the main guide:

1. [Mount LiDAR with 2 mm screws](ASSEMBLY.md#lidar-mounting)
2. [Seal gaps with silicone / hot glue](ASSEMBLY.md#weather-sealing-silicone-andor-hot-glue)
3. [Full enclosure section](ASSEMBLY.md#9-enclosure-assembly-v3-case)

**Next in build order:** [§7 Soldering](ASSEMBLY.md#7-soldering-the-harness) (you can print the case while waiting for Amazon parts).

---

## Quick troubleshooting

| Problem | Fix |
|---|-----|
| GitHub shows endless text | Normal — [download the file](#step-1--get-the-file-on-your-computer), do not read it in the browser |
| Slicer is empty after import | Zoom to fit; check you imported `.step` not a shortcut |
| Model is tiny or huge | Use slicer **scale** only if you know you need it — default should be mm |
| Ugly overhangs | Re-check orientation — **opening on the plate** |

**Back to start:** [README](../README.md)

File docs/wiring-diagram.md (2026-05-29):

# GooseEye wiring diagram

> **Where am I?** This is **step 2** on the [README build path](../README.md#the-build-path--follow-in-order). Read it **before** you solder, then continue to [§7 Soldering](ASSEMBLY.md#7-soldering-the-harness).

Keep this page open on a phone or second monitor while you wire the harness.

**Previous:** [Parts list](ASSEMBLY.md#4-bill-of-materials) · **Next:** [Print case](ASSEMBLY.md#3d-printing-the-case) or [Soldering](ASSEMBLY.md#7-soldering-the-harness)

---

## Block diagram

```mermaid
flowchart TB
  subgraph vehicle [Vehicle 12V]
    BAT[12V accessory or battery]
    FUSE[Inline fuse recommended]
  end

  subgraph power [5V power]
    BUCK[DC buck converter adjusted to 5.0V]
  end

  subgraph esp [XIAO ESP32-S3]
    X5V["5V / VBUS pad"]
    XGND[GND]
    D9[D9 UART TX]
    D10[D10 UART RX]
    D1[D1 MOSFET control]
  end

  subgraph switch [MOSFET module high-side]
    VIN[VIN+ from buck]
    OUT[OUT+ to LiDAR]
    IN[IN control from D1]
    SGND[Common GND]
  end

  subgraph lidar [Benewake TFmini]
    RED[Red VCC]
    BLK[Black GND]
    WHT[White RX]
    GRN[Green TX]
  end

  BAT --> FUSE --> BUCK
  BUCK --> X5V
  BUCK --> VIN
  BUCK --> SGND
  XGND --> SGND
  OUT --> RED
  BLK --> SGND
  D9 --> WHT
  D10 --> GRN
  D1 --> IN
```

## Connection table

| From | To | Wire color / label |
|---|-----|---|
| Vehicle 12 V+ (fused) | Buck `IN+` / `VIN+` | Red (main harness) |
| Vehicle 12 V− / chassis | Buck `IN−` / `GND` | Black |
| Buck 5 V output + | XIAO **5V / VBUS** (USB 5 V rail; not `3V3`) | |
| Buck 5 V output + | MOSFET `VIN+` / `DC+` | High-side input |
| Buck GND | XIAO `GND` | |
| Buck GND | MOSFET `GND` / `DC−` | |
| Buck GND | LiDAR black (GND) | Shared ground |
| MOSFET `OUT+` / switched + | LiDAR red (VCC) | **Do not** wire LiDAR VCC directly to buck |
| XIAO D9 (GPIO8) | LiDAR white (RX) | ESP TX → sensor RX |
| XIAO D10 (GPIO9) | LiDAR green (TX) | Sensor TX → ESP RX |
| XIAO D1 (GPIO2) | MOSFET `IN` / `PWM` / `CTRL` | Active-high = sensor on |

## TFmini cable colors

| Color | Function |
|---|---|
| Red | VCC (4.5–6 V) — through MOSFET |
| Black | GND |
| White | UART RX (into sensor) |
| Green | UART TX (out of sensor) |

## MOSFET module labels

Amazon and clone boards use different silkscreen text. Match function, not exact words:

| Common label | Role |
|---|---|
| `VIN+`, `DC+`, `IN+` | 5 V in from buck |
| `OUT+`, `LOAD+` | Switched 5 V to LiDAR red |
| `GND`, `DC−`, `VIN−` | Common with buck and XIAO |
| `IN`, `PWM`, `SIG`, `CTRL` | Control from XIAO D1 |

**Verify your board** with a multimeter before powering the LiDAR. Add a photo of your module to `docs/images/` when you have one.

## ASCII sketch (signal + power)

```
  12V ----[FUSE]----> BUCK IN+
  GND ---------------> BUCK IN-

  BUCK 5V+ -----+----> XIAO 5V / VBUS
                 |
                 +----> MOSFET VIN+
  BUCK GND ------+----> XIAO GND
                 +----> MOSFET GND
                 +----> LiDAR BLACK

  MOSFET OUT+ -----------> LiDAR RED

  XIAO D9  --------------> LiDAR WHITE
  XIAO D10 <-------------- LiDAR GREEN
  XIAO D1  --------------> MOSFET IN
```

## Important notes

- **Never apply 12 V to the XIAO or LiDAR.** Only 5 V regulated on **5V / VBUS** (not **3V3**).
- UART lines stay connected while the LiDAR is unpowered; firmware cuts VCC via the MOSFET in sleep mode.
- If LiDAR never powers on but UART works, check D1 wiring and whether your module is active-low (see troubleshooting in [ASSEMBLY.md](ASSEMBLY.md)).

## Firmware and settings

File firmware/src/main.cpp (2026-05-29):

// Goose Eye firmware entry point.
//
// XIAO ESP32-S3 + Benewake TFmini-S/Plus LiDAR.
// Reads the LiDAR at its native 100Hz, throttles BLE notifications to 20Hz.
// Sleep mode (breathing LED, LiDAR off) when disconnected or the app is not foreground.

#include <Arduino.h>

#include "ble_server.h"
#include "config.h"
#include "lidar.h"
#include "ota.h"
#include "pins.h"
#include "power.h"
#include "protocol.h"

namespace {

uint32_t g_lastNotifyMs = 0;
uint16_t g_smoothedMm   = 0;

// EMA smoothing — called on every valid LiDAR frame (~100 Hz) so the filter
// sees all samples, not just the 20 Hz notify subsample.
//
// alpha ≈ 0.2 at 100 Hz gives a time constant of ~50 ms, matching the old
// "alpha = 0.5 at 20 Hz" noise rejection while using 5× more data. The app
// (processor.ts) applies a second, user-configurable EMA on top.
//
// GE_FLAG_SMOOTHED is always set so the app knows the value has already been
// spike-filtered.
uint16_t smooth(uint16_t raw) {
    if (g_smoothedMm == 0) {
        g_smoothedMm = raw;
        return raw;
    }
    // Fixed-point alpha ≈ 0.2: new = (raw + 4 * old) / 5
    g_smoothedMm = (uint16_t)(((uint32_t)raw + 4u * (uint32_t)g_smoothedMm) / 5u);
    return g_smoothedMm;
}

uint8_t deriveQuality(uint16_t strength) {
    // TFmini strength: < 100 = unreliable, 100..2000 = good, > 2000 = great,
    // 65535 = saturated.
    if (strength == 0 || strength == 65535) return 0;
    if (strength < 100) return 10;
    if (strength < 500) return 40;
    if (strength < 2000) return 80;
    return 100;
}

} // namespace

void setup() {
    Serial.begin(115200);
    delay(200); // USB-CDC needs a moment
    Serial.println(F("[GooseEye] boot"));

    ge::Config::begin();
    ge::Lidar::begin(GE_LIDAR_RX_PIN, GE_LIDAR_TX_PIN);
    ge::Ota::begin();
    ge::BleServer::begin();
    ge::Power::begin();

    Serial.print(F("[GooseEye] advertising as "));
    Serial.println(ge::Config::get().name);
}

void loop() {
    ge::LidarFrame frame;
    bool newFrame = ge::Lidar::poll(frame);

    // Smooth every valid LiDAR frame (~100 Hz) so the filter sees all data.
    if (newFrame && frame.valid) {
        uint16_t mm = frame.distance_cm * 10;
        smooth(mm);
    }

    // Only push notifications while a central is subscribed.
    if (ge::BleServer::isStreaming() && !ge::Ota::inProgress()) {
        uint32_t now = millis();
        if (now - g_lastNotifyMs >= GE_DISTANCE_NOTIFY_MS) {
            g_lastNotifyMs = now;
            ge::LidarFrame latest = ge::Lidar::latest();

            const bool fresh = latest.valid &&
                               (now - latest.timestamp_ms) <= GE_LIDAR_MAX_AGE_MS;

            ge_distance_payload_t payload = {};
            if (fresh) {
                payload.distance_mm = g_smoothedMm;
                payload.strength    = latest.strength;
                payload.quality     = deriveQuality(latest.strength);
                payload.flags       = GE_FLAG_SMOOTHED;
                if (latest.distance_cm == 0 || latest.strength < 100 ||
                    latest.strength == 65535) {
                    payload.flags |= GE_FLAG_OUT_OF_RANGE;
                }
                if (latest.distance_cm < 10) {
                    payload.flags |= GE_FLAG_TOO_CLOSE;
                }
            } else {
                payload.flags = GE_FLAG_OUT_OF_RANGE;
                g_smoothedMm = 0;
            }
            ge::BleServer::notifyDistance(
                reinterpret_cast<uint8_t*>(&payload), sizeof(payload)
            );
        }
    } else {
        // Drop the smoothing state when nobody's listening so the next session
        // starts clean.
        g_smoothedMm = 0;
    }

    ge::Power::tick();
    ge::BleServer::loop();
    delay(2); // small yield -- TFmini frames arrive every 10ms at 100Hz
}

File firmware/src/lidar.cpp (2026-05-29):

#include "lidar.h"
#include <HardwareSerial.h>

namespace ge {

namespace {

// Use UART1 on the XIAO ESP32-S3. UART0 is reserved for USB-CDC console.
HardwareSerial g_serial(1);

LidarFrame g_latest = {0, 0, 0, 0, false};

int      g_rxPin   = -1;
int      g_txPin   = -1;
uint32_t g_baud    = 115200;
bool     g_enabled = false;

// Parser state.
enum ParseState : uint8_t {
    WAIT_HEADER1,
    WAIT_HEADER2,
    READING_PAYLOAD,
};

ParseState g_state = WAIT_HEADER1;
uint8_t    g_buf[9];
uint8_t    g_bufIdx = 0;

bool checksumOk(const uint8_t* frame) {
    uint16_t sum = 0;
    for (int i = 0; i < 8; ++i) sum += frame[i];
    return (uint8_t)(sum & 0xFF) == frame[8];
}

void resetParser() {
    g_state  = WAIT_HEADER1;
    g_bufIdx = 0;
    g_latest = {0, 0, 0, 0, false};
}

} // namespace

void Lidar::begin(int rxPin, int txPin, uint32_t baud) {
    g_rxPin = rxPin;
    g_txPin = txPin;
    g_baud  = baud;
    // UART enabled by LidarPower when awake.
    setEnabled(false);
}

void Lidar::setEnabled(bool enabled) {
    if (enabled == g_enabled) return;

    g_enabled = enabled;
    if (enabled) {
        // Note: HardwareSerial.begin signature is (baud, config, rxPin, txPin).
        // rxPin = ESP32 RX (connected to TFmini TX),
        // txPin = ESP32 TX (connected to TFmini RX).
        g_serial.begin(g_baud, SERIAL_8N1, g_rxPin, g_txPin);
        resetParser();
    } else {
        g_serial.end();
        resetParser();
    }
}

bool Lidar::poll(LidarFrame& outFrame) {
    if (!g_enabled) return false;

    bool newFrame = false;

    while (g_serial.available() > 0) {
        uint8_t b = (uint8_t)g_serial.read();

        switch (g_state) {
            case WAIT_HEADER1:
                if (b == 0x59) {
                    g_buf[0] = b;
                    g_state  = WAIT_HEADER2;
                }
                break;

            case WAIT_HEADER2:
                if (b == 0x59) {
                    g_buf[1] = b;
                    g_bufIdx = 2;
                    g_state  = READING_PAYLOAD;
                } else {
                    // Unexpected byte; resync from the start.
                    g_state = WAIT_HEADER1;
                }
                break;

            case READING_PAYLOAD:
                g_buf[g_bufIdx++] = b;
                if (g_bufIdx >= 9) {
                    if (checksumOk(g_buf)) {
                        LidarFrame f;
                        f.distance_cm  = (uint16_t)g_buf[2] | ((uint16_t)g_buf[3] << 8);
                        f.strength     = (uint16_t)g_buf[4] | ((uint16_t)g_buf[5] << 8);
                        f.temperature  = (uint16_t)g_buf[6] | ((uint16_t)g_buf[7] << 8);
                        f.timestamp_ms = millis();
                        f.valid        = true;
                        g_latest       = f;
                        outFrame       = f;
                        newFrame       = true;
                    }
                    g_state  = WAIT_HEADER1;
                    g_bufIdx = 0;
                }
                break;
        }
    }

    return newFrame;
}

LidarFrame Lidar::latest() {
    return g_latest;
}

} // namespace ge

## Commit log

2026-05-29 Initial hardware repo: firmware, assembly guide, MOSFET power control.
    ESP32-S3 firmware for XIAO + TFmini with LiDAR rail switched in sleep mode.
    Includes BOM links, wiring diagrams, soldering instructions, and flash scripts.
    [partitions.csv, v3 Case.step]
2026-05-29 Document v3 enclosure: LiDAR on 2mm screws, lid against truck bed.
    Add assembly section for Case.step layout, internal wiring, and bottom harness exit.
2026-05-29 Add slicer import and print orientation for v3 case STEP.
2026-05-29 Clarify XIAO power pad: 5V/VBUS silkscreen, not 3V3.
    Builders may see VBUS instead of 5V on the Seeed XIAO ESP32-S3.
2026-05-29 Document U.FL WiFi antenna install on XIAO ESP32-S3.
2026-05-29 Rewrite README as beginner start-here path with chained links.
    Assume no GitHub, soldering, or terminal experience; add guide map and
    next-step navigation throughout assembly docs.
2026-05-29 Document silicone and hot glue sealing for case gaps and wire exit.
2026-05-29 Add PRINT-THE-CASE guide so STEP file is not mistaken for code.
2026-05-29 Put full build requirements before parts list; emphasize 3D print option.
